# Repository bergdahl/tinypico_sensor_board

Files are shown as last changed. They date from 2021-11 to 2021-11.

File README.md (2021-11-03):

# tinypico_sensor_board

This is a small motherboard for the TinyPICO to connect sensors to a QWIIC/STEMMA QT or Grove connector.

It supports three different configurations for the voltage on the connectors, to suppport the maximum number of sensors.

 - 3.3V power - 3.3V signal
 - 5V power, 3.3V signal
 - 5V power, 5V signal

See the PDF file for configuration options.

# Schema

See the PDF file for schematics.

# PCB

Designfiles in EAGLE format can be found in the `PCB` folder. Gerber files can be found in the `PCB/Gerbers` folder.

# Firmwares

Firmware for connecting the sensors to MQTT is present in the `firmware` folder.

TODO: Add more firmware.

## Connectors

The QWIIC/Stemma QT port is connected to the default I2C pins of the TinyPICO, GPIO21 and GPIO22. 

The Grove connector is connected to GPIO4 and GPIO5, so to use I2C you need initialize it with `Wire.Begin(5, 4)`.

Note that the ESP32 allows you to assign any function to any pin, so any communication type is possible, like UART.

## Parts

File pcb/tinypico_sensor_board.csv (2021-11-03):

Part | Value | Device | Package | Description
C1 | 100nF | CAPC0603 | C0603
H1 | MOUNTHOLE-PAD3.2 | MOUNTHOLE-PAD3.2 | 3.2-PAD
H2 | MOUNTHOLE-PAD3.2 | MOUNTHOLE-PAD3.2 | 3.2-PAD
H3 | MOUNTHOLE-PAD3.2 | MOUNTHOLE-PAD3.2 | 3.2-PAD
H4 | MOUNTHOLE-PAD3.2 | MOUNTHOLE-PAD3.2 | 3.2-PAD
J2 | GROVE-CONNECTOR-2PAD4UCON17312 | GROVE-CONNECTOR-2PAD4UCON17312 | 4UCON17312
Q1 | SSM3K16FU | MOSFET-NCHSOT323 | SOT323
Q2 | SSM3K16FU | MOSFET-NCHSOT323 | SOT323
Q3 | SSM3K16FU | MOSFET-NCHSOT323 | SOT323
Q4 | SSM3K16FU | MOSFET-NCHSOT323 | SOT323
R1 | 10K | RESISTOR0603 | R0603
R2 | 10K | RESISTOR0603 | R0603
R3 | 10K | RESISTOR0603 | R0603
R4 | 10K | RESISTOR0603 | R0603
R5 | 10K | RESISTOR0603 | R0603
R6 | 10K | RESISTOR0603 | R0603
R7 | 10K | RESISTOR0603 | R0603
R8 | 10K | RESISTOR0603 | R0603
R9 | 0R | RESISTOR0603 | R0603
R10 | 0R | RESISTOR0603 | R0603
R11 | 0R | RESISTOR0603 | R0603
R12 | 0R | RESISTOR0603 | R0603
R13 | 0R | RESISTOR1206 | R1206
R14 | 0R | RESISTOR1206 | R1206
R15 | 0R | RESISTOR1206 | R1206
R16 | 0R | RESISTOR1206 | R1206
U1 | TINYPICO | TINYPICO | TINYPICO
X4 | QWIIC | QWIICRA | JST-SH-4-SMD-RA

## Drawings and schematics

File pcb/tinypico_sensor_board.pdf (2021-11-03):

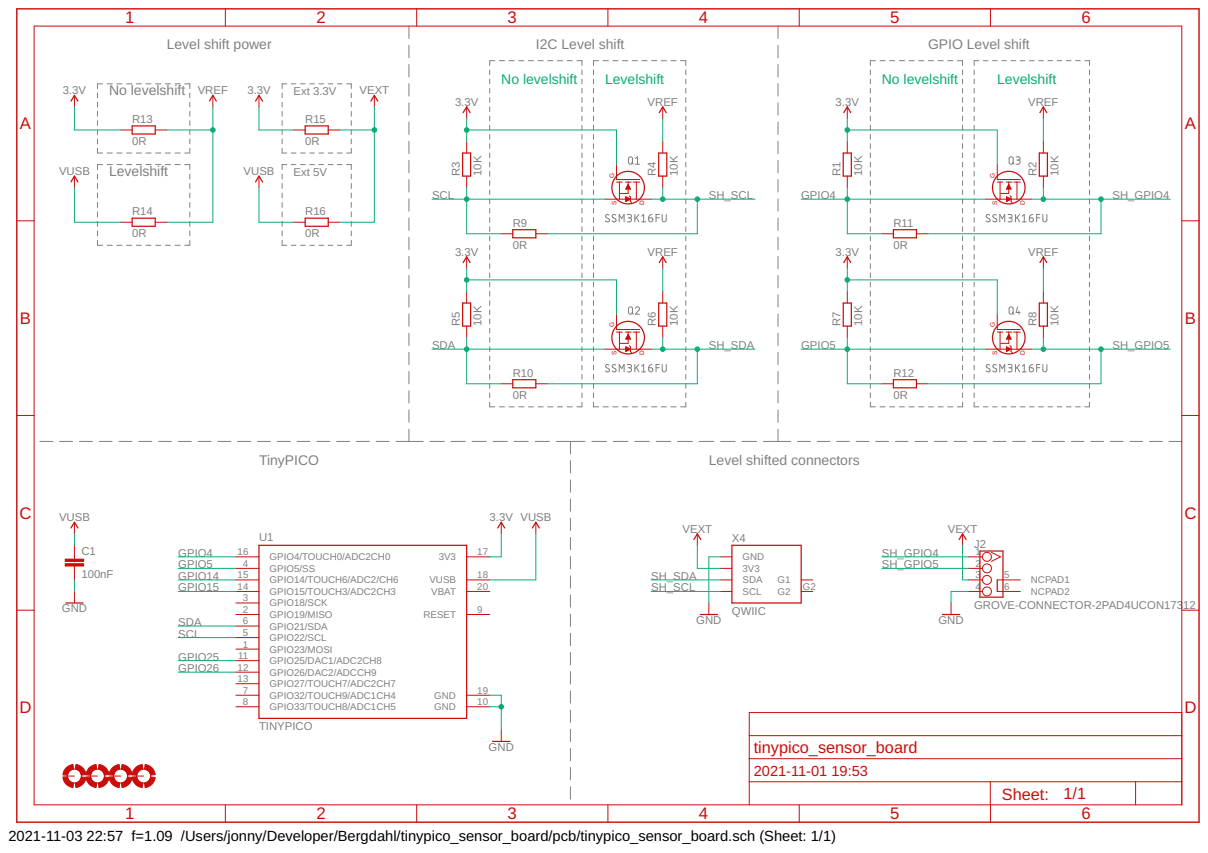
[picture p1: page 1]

2021-11-03 22:57 f=1.09 /Users/jonny/Developer/Bergdahl/tinypico_sensor_board/pcb/tinypico_sensor_board.sch (Sheet: 1/1)

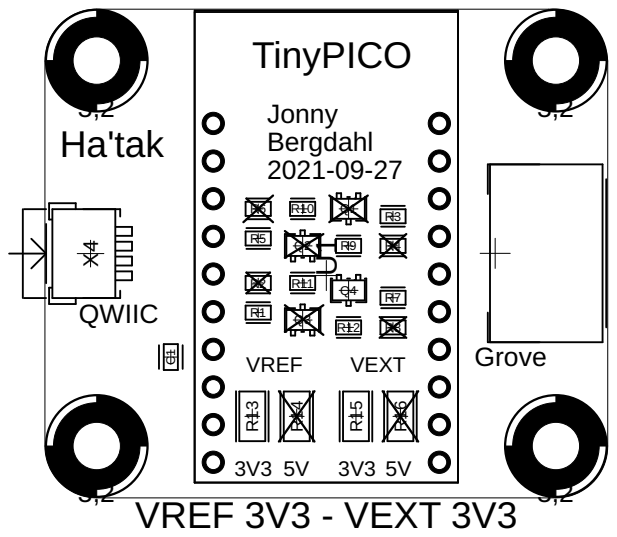
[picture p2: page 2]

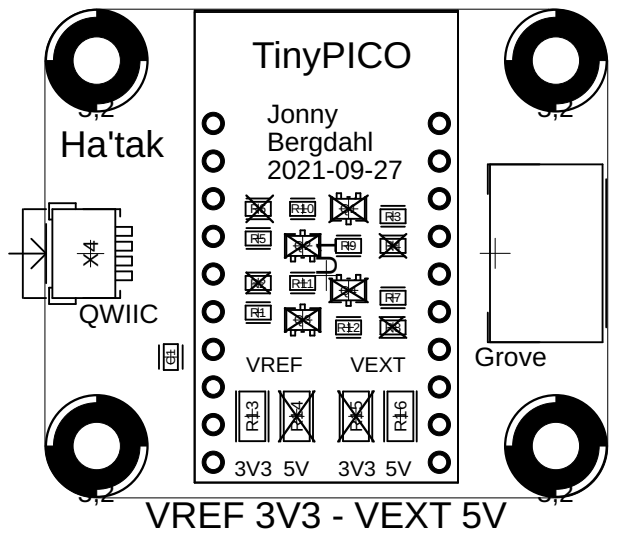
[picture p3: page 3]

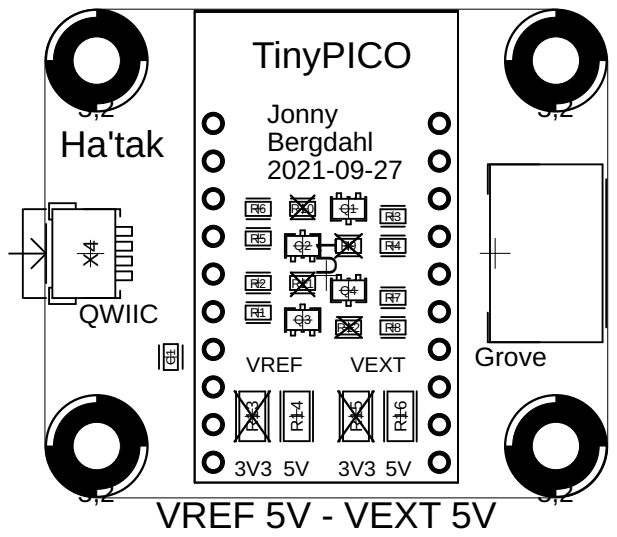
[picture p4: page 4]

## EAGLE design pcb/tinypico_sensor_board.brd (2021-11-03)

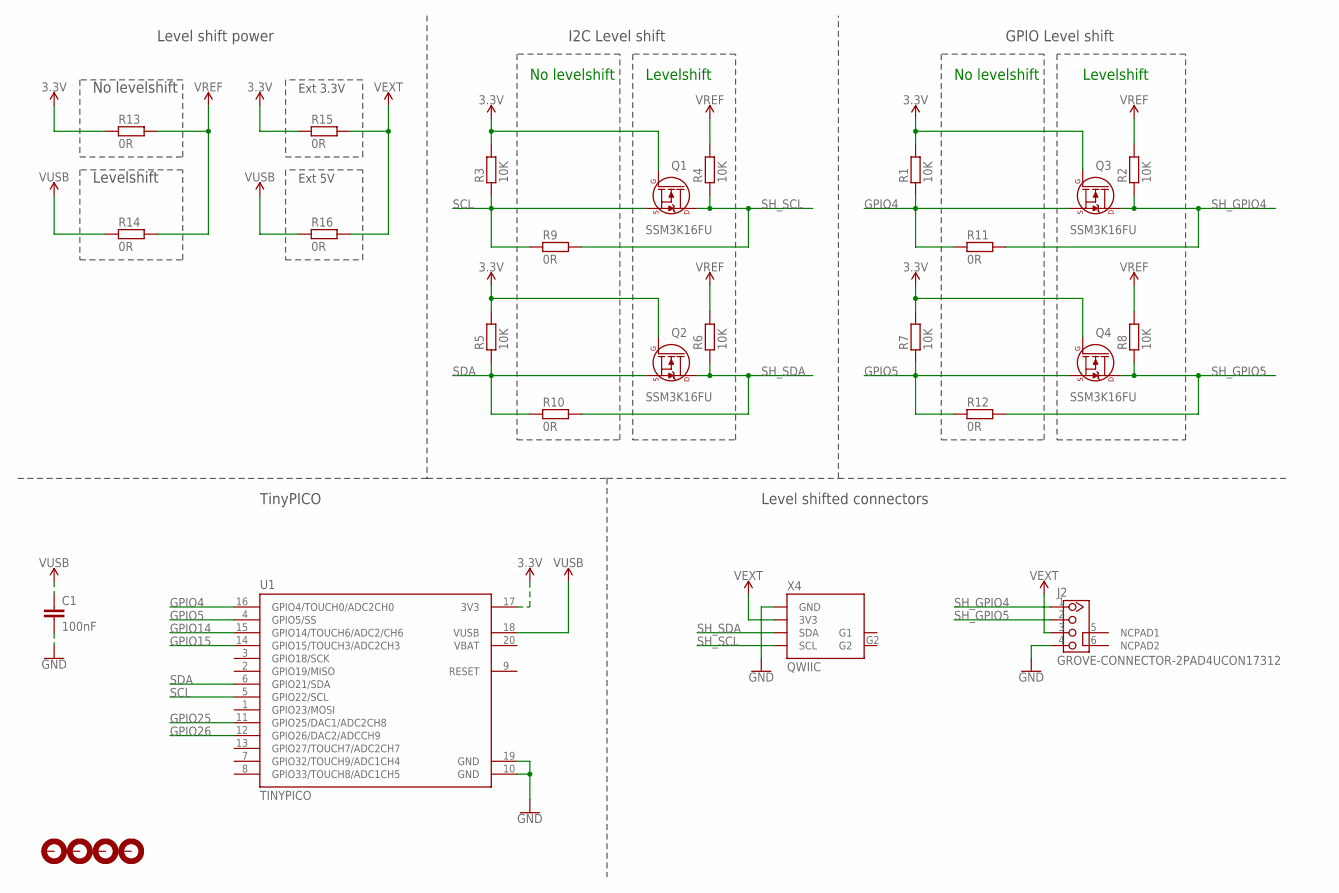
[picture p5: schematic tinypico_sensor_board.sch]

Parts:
C1: 100nF; C0603
H1, H2, H3, H4: MOUNTHOLE-PAD3.2; 3.2-PAD
J2: GROVE-CONNECTOR-2PAD4UCON17312; 4UCON17312
Q1, Q2, Q3, Q4: SSM3K16FU; SOT323
R1, R2, R3, R4, R5, R6, R7, R8: 10K; R0603
R9, R10, R11, R12: 0R; R0603
R13, R14, R15, R16: 0R; R1206
U1: TINYPICO
X4: QWIIC; JST-SH-4-SMD-RA

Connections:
3.3V: Q1.1 (G), Q2.1 (G), Q3.1 (G), Q4.1 (G), R1.2, R3.2, R5.2, R7.2, R13.1, R15.1, U1.17 (3V3)
GND: C1.2, J2.4 (GND), U1.10 (GND), U1.19 (GND), X4.GND
GPIO4: Q3.2 (S), R1.1, R11.1, U1.16 (GPIO4/TOUCH0/ADC2CH0)
GPIO5: Q4.2 (S), R7.1, R12.1, U1.4 (GPIO5/SS)
GPIO14: U1.15 (GPIO14/TOUCH6/ADC2/CH6)
GPIO15: U1.14 (GPIO15/TOUCH3/ADC2CH3)
GPIO25: U1.11 (GPIO25/DAC1/ADC2CH8)
GPIO26: U1.12 (GPIO26/DAC2/ADCCH9)
SCL: Q1.2 (S), R3.1, R9.1, U1.5 (GPIO22/SCL)
SDA: Q2.2 (S), R5.1, R10.1, U1.6 (GPIO21/SDA)
SH_GPIO4: J2.1 (SCL), Q3.3 (D), R2.1, R11.2
SH_GPIO5: J2.2 (SDA), Q4.3 (D), R8.1, R12.2
SH_SCL: Q1.3 (D), R4.1, R9.2, X4.SCL
SH_SDA: Q2.3 (D), R6.1, R10.2, X4.SDA
VEXT: J2.3 (VCC), R15.2, R16.2, X4.3V3
VREF: R2.2, R4.2, R6.2, R8.2, R13.2, R14.2
VUSB: C1.1, R14.1, R16.1, U1.18 (VUSB)

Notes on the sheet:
TinyPICO
No levelshift
Levelshift
I2C Level shift
GPIO Level shift
Level shift power
Level shifted connectors
Ext 3.3V
Ext 5V

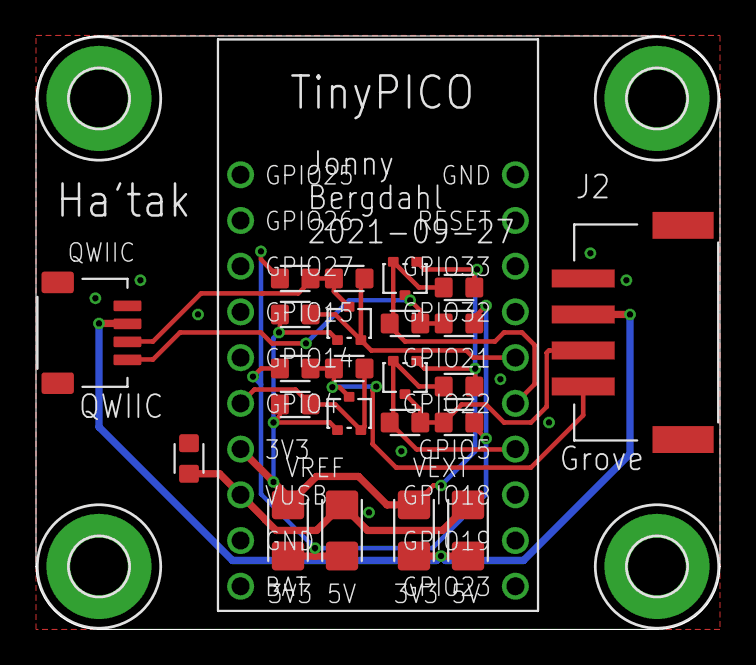
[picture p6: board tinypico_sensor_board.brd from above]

Board: 2 copper layers, 38.0 x 33.0 mm, 28 parts (0 on the bottom side), 13 nets.

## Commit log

2021-11-03 Final version of PCB
    [tinypico_sensor_board.GBL, tinypico_sensor_board.GBO, tinypico_sensor_board.GBP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]
2021-11-03 Updated Gerber files
    [tinypico_sensor_board.GBL, tinypico_sensor_board.GBO, tinypico_sensor_board.GBP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]
